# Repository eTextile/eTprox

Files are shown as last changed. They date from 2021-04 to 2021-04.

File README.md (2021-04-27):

# eTprox
## eTextile Proximity Switch

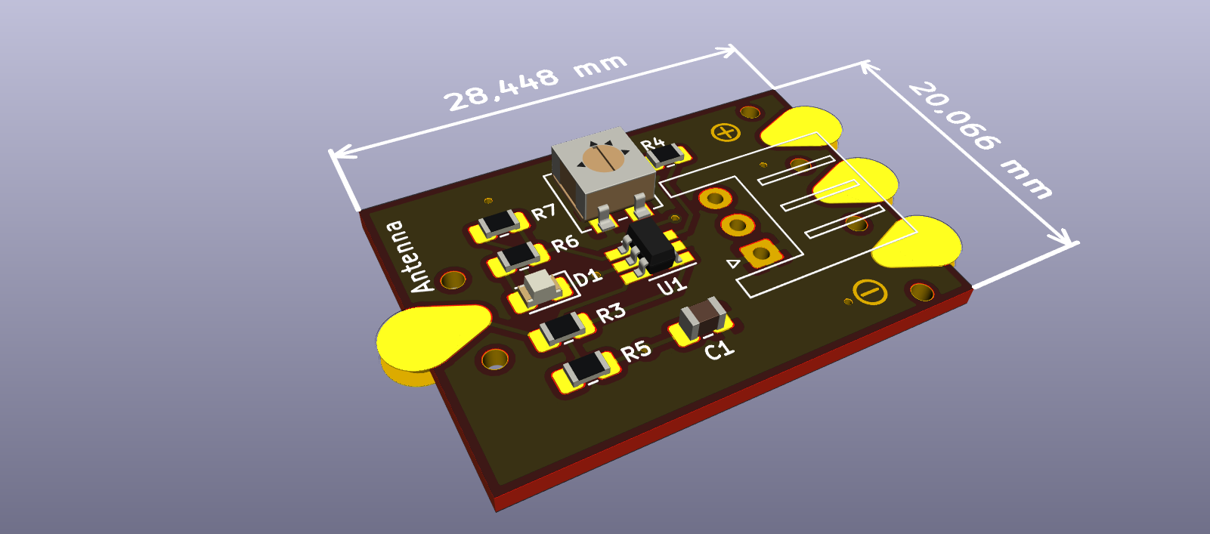
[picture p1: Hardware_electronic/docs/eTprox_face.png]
eTprox_face


### Credits
- **Wendy Van Wynsberghe** <wendy[AT]constantvzw.org>
- **License** : Cern Open Hardware (see the License file)
- **wenPage** : http://etextile-summercamp.org/swatch-exchange/sewable-proximity-switch-board-1/
- **Repository**: https://github.com/eTextile/eTprox/tree/master

### The story
"What happens when you have been working with tactile textile and touch in this era, where transmission of viral particles is a hot topic? Working with the MPR121 board? You stop and think it over. During the hard lockdown in May I started to think about tactility and proximity, activating without touching. I could not imagine a public touching the installation I was building. I researched already existing boards and possibilities and I didn’t find what I wanted. I dove into the realms of all kinds of chips and circuits. Infrared, ultrasonic, time of flight – they are all sensors that handle proximity and distance but they do not turn your conductive textile into a tactile interactive object. My second find was bingo: the MTCH101 chip, is a switch, that means it turns something on and off, it makes your conductive textile into a button by hovering over it. In the words of the company that makes them: the MTCH101 is a low cost single channel capacitive proximity detector. The distance of activation and the sensitivity depends on the voltage you give it and the surface of your conductive antenna. The activation can even happen with a non conductive layer covering it. If the switch has a temporary glitch, it recalibrates itself very fluently."

## BOM
- PCB with SMD components
- eTextile antenna (conductive thread or conductive textile)
- Microcontroller (not included)

| Référence | Def (Kicad components names) | Quantity | Value |
|:---|:---|---|:---|
|  J2	 | JST_XH_S3B-XH-A_1x03_P2.50mm_Horizontal	 | 1 | |
|  RV1	 | Potentiometer_Vishay_TS53YJ_Vertical	 | 1	  | 10K |
|  U1	 | SOT-23-6_Handsoldering	 | 1	  | MTCH101 | 
|  D1	 | LED_0805_2012Metric_Pad1.15x1.40mm_HandSolder | 1	  | LED |
|  C1	 | C_0805_2012Metric_Pad1.18x1.45mm_HandSolder | 1	  | 0.1µF |
|  R7,R3	 | R_0805_2012Metric_Pad1.20x1.40mm_HandSolder | 2	  | 4.7K |
|  R6	 | R_0805_2012Metric_Pad1.20x1.40mm_HandSolder | 1	  | 1K |
|  R5,R4	 | R_0805_2012Metric_Pad1.20x1.40mm_HandSolder | 2	  | 10K |

## Credits
Design forked from Knottex project @ Timelab.

# TODO
- See : http://www.farnell.com/datasheets/1714150.pdf

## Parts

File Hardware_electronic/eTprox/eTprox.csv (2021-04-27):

Id | Référence | Boîtier | Quantité | Désignation | Fournisseur et réf
1 | J2 | JST_XH_S3B-XH-A_1x03_P2.50mm_Horizontal | 1 | Conn_01x03
2 | Antenna | eTprox_Pad_1x01 | 1 | Conn_01x01
3 | RV1 | Potentiometer_Vishay_TS53YJ_Vertical | 1 | 10K
4 | J1 | eTprox_Pad_1x03 | 1 | Conn_01x03
5 | U1 | SOT-23-6_Handsoldering | 1 | MTCH101
6 | D1 | LED_0805_2012Metric_Pad1.15x1.40mm_HandSolder | 1 | LED
7 | C1 | C_0805_2012Metric_Pad1.18x1.45mm_HandSolder | 1 | 0.1µF
8 | R7,R3 | R_0805_2012Metric_Pad1.20x1.40mm_HandSolder | 2 | 4.7K
9 | R6 | R_0805_2012Metric_Pad1.20x1.40mm_HandSolder | 1 | 1K
10 | R5,R4 | R_0805_2012Metric_Pad1.20x1.40mm_HandSolder | 2 | 10K

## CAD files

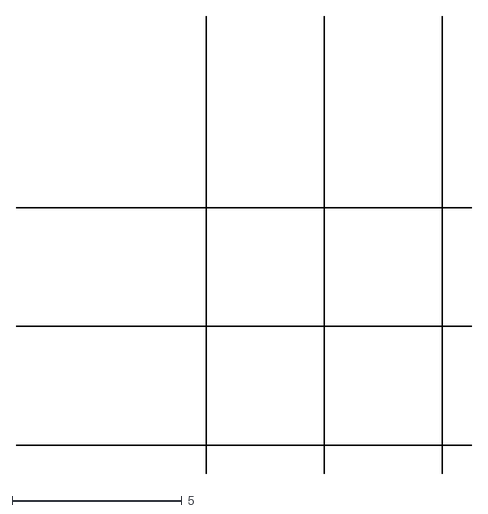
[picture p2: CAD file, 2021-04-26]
Hardware_electronic/docs/PCB_symbols/logo.dxf
13.4 x 13.5

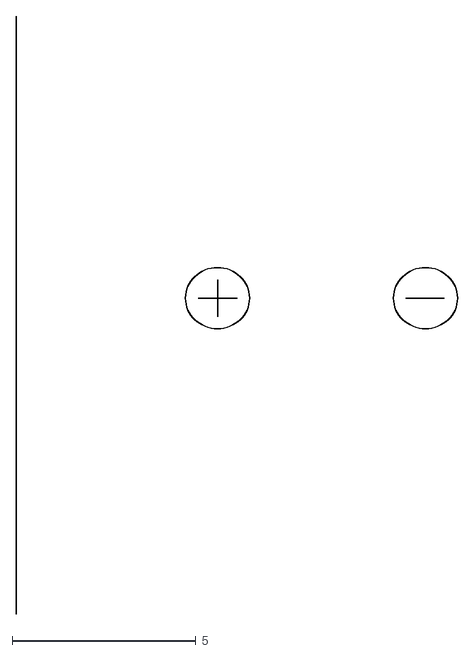
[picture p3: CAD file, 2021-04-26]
Hardware_electronic/docs/PCB_symbols/polarity.dxf
12.0 x 16.3

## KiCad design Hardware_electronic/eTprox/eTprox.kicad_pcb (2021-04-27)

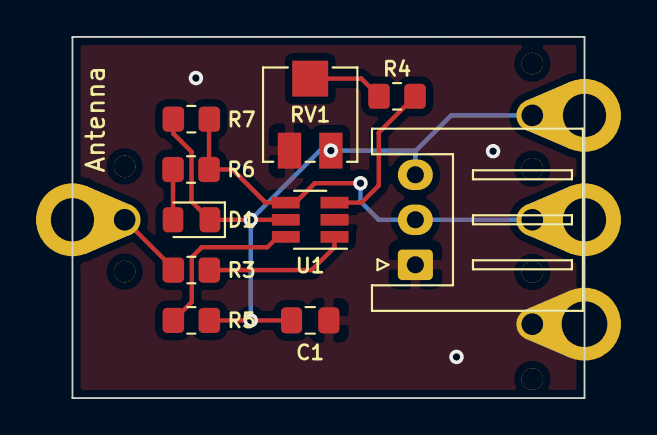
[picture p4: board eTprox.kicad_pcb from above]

Board: 2 copper layers, 28.4 x 20.1 mm, 12 parts (0 on the bottom side), 9 nets.

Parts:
Antenna: Conn_01x01; eTprox_Pad_1x01
C1: 0.1µF; C_0805_2012Metric_Pad1.18x1.45mm_HandSolder
D1: LED; LED_0805_2012Metric_Pad1.15x1.40mm_HandSolder
J1: Conn_01x03; eTprox_Pad_1x03
J2: Conn_01x03; JST_XH_S3B-XH-A_1x03_P2.50mm_Horizontal
R3, R7: 4.7K; R_0805_2012Metric_Pad1.20x1.40mm_HandSolder
R4, R5: 10K; R_0805_2012Metric_Pad1.20x1.40mm_HandSolder
R6: 1K; R_0805_2012Metric_Pad1.20x1.40mm_HandSolder
RV1: 10K; Potentiometer_Vishay_TS53YJ_Vertical
U1: MTCH101; SOT-23-6_Handsoldering

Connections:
GND: C1.2, J1.3, J2.1, RV1.3, U1.2
unnamed: Antenna.1, R3.1
unnamed: D1.2, R6.1
unnamed: R3.2, U1.1
unnamed: R4.1, RV1.2
unnamed: R4.2, U1.3
unnamed: R5.1, U1.6
SIG: J1.2, J2.2, R6.2, R7.2, U1.4
VCC: C1.1, D1.1, J1.1, J2.3, R5.2, R7.1, RV1.1, U1.5

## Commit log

2021-04-27 Added JST plug
    [eTprox.kicad_pcb, eTprox.sch]
2021-04-27 Added polarity
    [eTprox.kicad_pcb, eTprox.sch]
2021-04-27 Added BOM
    [eTprox-B.Cu.gbr, eTprox-B.Mask.gbr, eTprox-B.SilkS.gbr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]

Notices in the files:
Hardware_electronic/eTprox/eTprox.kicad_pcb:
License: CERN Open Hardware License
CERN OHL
